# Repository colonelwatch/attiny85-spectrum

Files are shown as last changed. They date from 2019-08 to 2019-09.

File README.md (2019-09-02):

# attiny85-spectrum

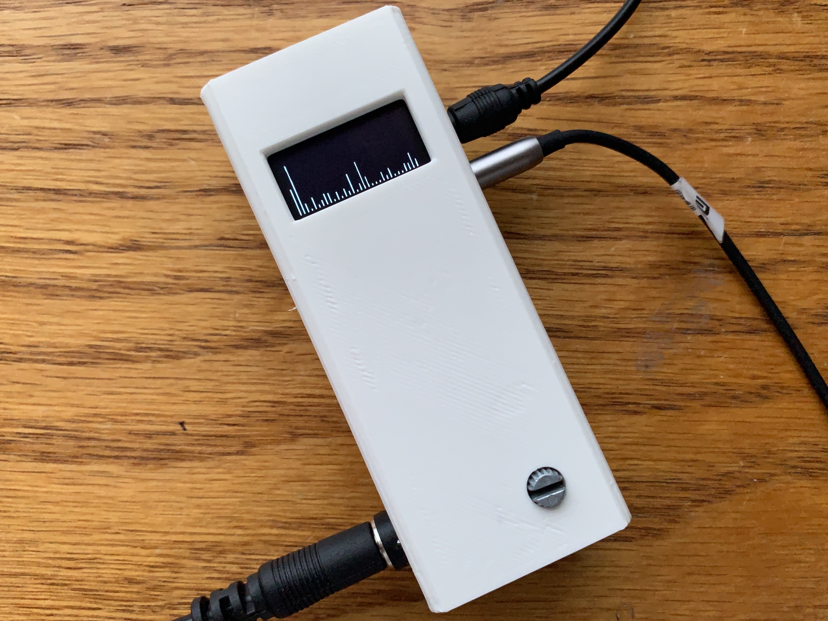
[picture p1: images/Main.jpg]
Main Image


The goal of this project is to get smooth, appealing music visualization on the ATTiny85, optimizing around its limited speed and resources (RAM and program memory). Its on ongoing personal project right now which is mostly complete (outside help is still welcome!), but it's otherwise fully functional and ready to be flashed. Some special steps are required, however, and will be listed below. *Thanks goes to redditors stockvu and mashuptwice for their input on time-smoothing.*

## Explanation
The linchpins to enabling music visualization with an ATTiny85 are two libraries: 

- kosme's AVR implementation of [fix_fft](https://github.com/kosme/fix_fft), a faster 8-bit integer-based FFT
- lexus2k's [ssd1306](https://github.com/lexus2k/ssd1306) library and its nanoengine API, which outputs to the OLED in 32x32 chunks because the ATTiny85 can't hold the entire screen in memory

I had to change the pin assignments in the ssd1306 library to free up an analog-capable pin, ~~and in the fix_fft library I changed the char type buffers into int8_t ones~~. Both modified libraries are availible, and they must be placed in the Arduino libraries folder, overwriting the original ones (keep a backup!). *Recently kosme has updated the fix_fft library to int8_t defintions as well, __I have now included his latest commit instead__.* Additionally, I raised the OSCCAL value to 250, giving me an internal clock of about 30MHz. It's usually used for clock calibration, but it has been used successfully for overclocking. However, it's only found on the ATTiny85 and a few other Atmel MCUs.

The core of the program is a loop of this:

1. The music is sampled with the ADC at pin 3/A3, which is then mapped to the range that int8_t covers (0 to 1023 -> -128 to 127)
     * A prescaler of ~~16~~ 32 gives a sampling frequency of about ~~2MHz~~ *now 1MHz* (considering the overclock), so empty while loops are used to maintain the user-set sampling frequency
2. The average value is subtracted from all samples. This lets the first band represent extremely low frequencies, rather than being swamped with the DC bias
3. The "fix_fftr" function, which runs twice as fast as and uses half the memory of the "fix_fft" version because it doesn't need imaginary data
4. The output is reordered, cut off below 0, scaled up, and time-smoothed using the previous output and fixed factors
5. The modified output is fed into the OLED part-by-part using the nanoengine API

## Components

- ATTiny85
- SSD1306 OLED Module
- 3-Pole Audio Jack (1, 2 for pass-through)
- 2N3904 or other NPN transistor
- 0.1uF Capacitor
- Potentiometer, any value above 10k
- 200 Ohm Resistor (2)
- 820 Ohm Resistor
- 100k Ohm Resistor
- External 5V Power Supply

## Schematic

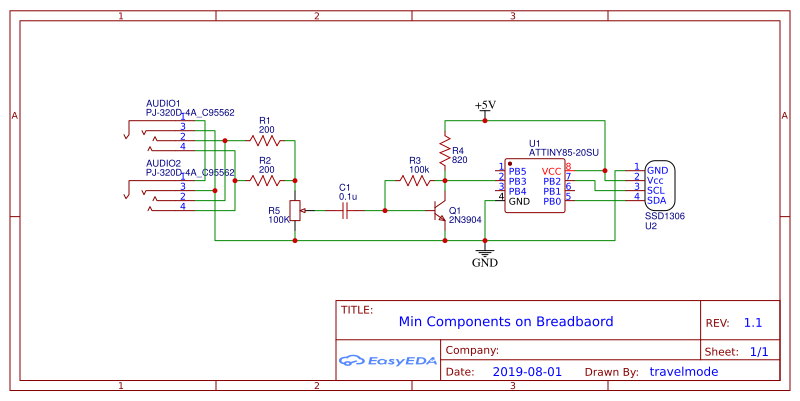
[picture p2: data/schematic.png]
Schematic


## Demonstration

attiny85-spectrum demonstration (https://www.youtube.com/watch?v=iyPTCbWjp_4)

### Enclosure

The STL of the enclosure in the video is included in this repo. Printed on a Monoprice Select Mini V2. See [this](images/Inside.jpg) picture for component placements on a 3x7 protoboard. *Note: The barrel connector wire colors were accidentally swapped—red is ground, and black is 5V. Please correct this if you intend to replicate the entire project!*

## Limitations/TO-DO

- The fix_fft library uses linear scaling for both frequency and power... and without much resolution in either / ~~*No room for logarithmic scaling? TO-DO: Attempt to implement later.*~~
- The OLED display regularly shows detached bars that only really appear in still photos / *TO-DO: Find out why*
    - Apparently has reduced intensity now with recent code changes. Still unexplained though.

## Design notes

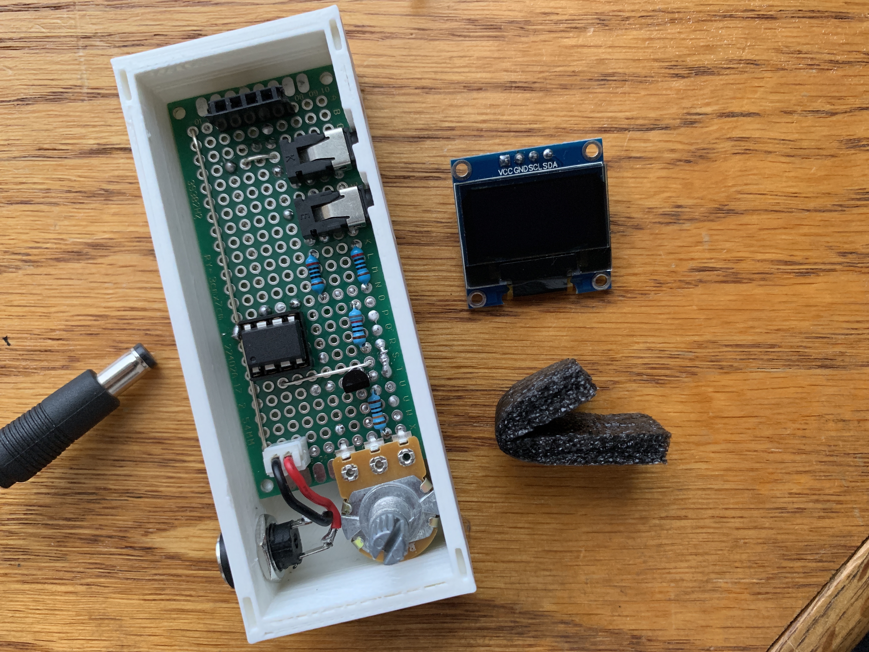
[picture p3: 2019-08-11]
images/Inside.jpg

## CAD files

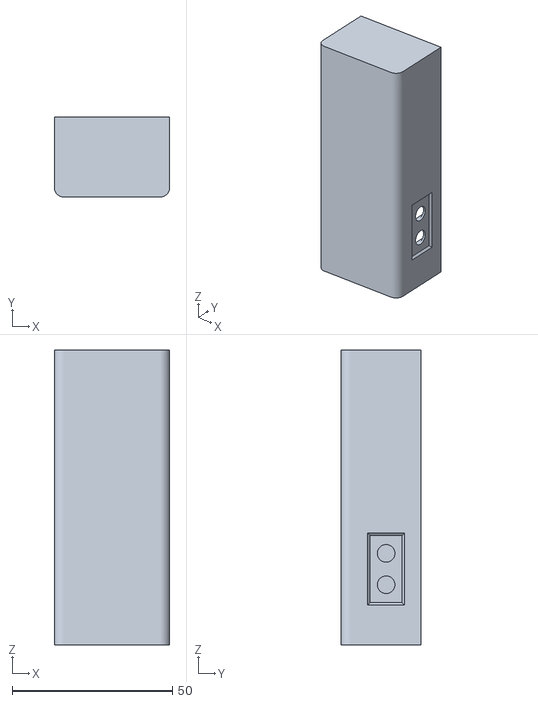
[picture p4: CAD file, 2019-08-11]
data/OLED Spectrum Body.stl
36.0 x 25.0 x 92.0

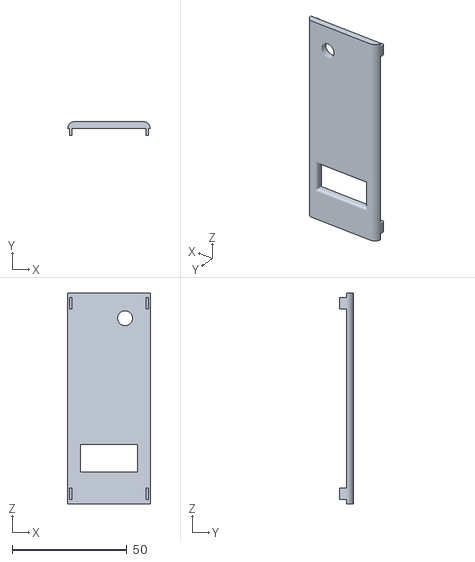
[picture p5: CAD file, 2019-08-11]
data/OLED Sprectrum Front.stl
36.0 x 6.00 x 92.0

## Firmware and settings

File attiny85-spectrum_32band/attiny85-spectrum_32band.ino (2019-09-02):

// Copyright [2019] [colonelwatch]

#include "fix_fft.h"                  // 8-bit FFT library modified for Arduino
#include "ssd1306.h"                  // library for OLED
#include "nano_engine.h"              // library for nanoengine (which draws sector-by-sector on OLED because the ATtiny85 can't hold a full buffer)

// To get this program to operate, the SDA and SCL pins must be reassigned to 0 and 2 respectively in the library header file
// The file is located in libraries\ssd1306\src\intf\i2c\ssd1306_i2c_conf.h
// Make sure to undo this if the library will be used again in the future

// These are user-adjustable
//#define LOG_OUTPUT              // Uncomment to enable logarithmic output (exchanges absolute resoluton for more readable output; may require different below params)
#define SAMPLING_FREQUENCY 15000  // Sampling frequency (Actual max measured frequency captured is half)
#define TIME_FACTOR 3             // Smoothing factor (lower is more dynamic, higher is smoother) ranging from 1 to 10+
#define SCALE_FACTOR 8           // Direct scaling factor (raise for higher bars, lower for shorter bars)

#ifdef LOG_OUTPUT
const float log_scale = 64./log(64./SCALE_FACTOR + 1.);                              // Attempts to create an equivalent to SCALE_FACTOR for log function
#endif
const float coeff = 1./TIME_FACTOR;                                                  // Time smoothing coefficients (used to factor in previous data)
const float anti_coeff = (TIME_FACTOR-1.)/TIME_FACTOR;
const unsigned int sampling_period_us = round(1000000 * (2.0 / SAMPLING_FREQUENCY)); // Sampling period (doubled to account for overclock)

int8_t data[64], buff[32];                                     // used to store FFT input/output and past data
unsigned long microseconds;                                    // used for timekeeping
int summ, avg;                                                 // used for DC bias elimination

NanoEngine<TILE_32x32_MONO> engine;                            // declares nanoengine

void setup()
{
  OSCCAL = 250; // Overclocks the MCU to around 30 MHz, set lower if this causes instability, raise if you can/want
  
  ADCSRA &= ~(bit (ADPS0) | bit (ADPS1) | bit (ADPS2));       // clear ADC prescaler bits
  ADCSRA |= bit (ADPS2);                                      // sets ADC clock in excess of 10kHz
  ADCSRA |= bit (ADPS0);

  ssd1306_128x64_i2c_init();                                  // initializes OLED
  ssd1306_clearScreen();                                      // clears OLED
  
  engine.begin();                                             // inititalizes nanoengine
};

void loop()
{
  summ = 0;
  for (int i = 0; i < 64; i++) {
    microseconds = micros();
    
    data[i] = ((analogRead(A3)) >> 2) - 128;                        // Fitting analogRead data (range:0 - 1023) to int8_t array (range:-128 - 127)
    summ += data[i];
    while (micros() < (microseconds + sampling_period_us)) {        // Timing out uC ADC to fulfill sampling frequency requirement
    }
  }

  // Eliminating remaining DC component (produces usable data in FFT bin #0, which is usually swamped by DC bias)
  avg = summ/64;
  for (int i = 0; i < 64; i++){
    data[i] -= avg;
  }
    
  fix_fftr(data, 6, 0);                             // Performing real FFT

  // Reordering the data so that the left/right halves become odd/even, based on apparent fix_fftr output
  // Seems to make it more accurate (proper response to a frequency sweep with some aliasing)
  {int8_t reordered[32];  // <-- This array as a global variable causes instablity, so it's declared in a minimal scope
    for(int i = 0; i < 32; i++){
    if(i % 2 != 0) reordered[i] = data[i/2+16];
    else reordered[i] = data[i/2];
  }for(int i = 0; i < 32; i++) data[i] = reordered[i];}
  
  // Time smoothing by user-determined factor and user-determined scaling
  for(int count = 0; count < 32; count++){
  if(data[count] < 0) data[count] = 0;                                          // Eliminating negative output of fix_fftr
  #ifdef LOG_OUTPUT
  else data[count] = log_scale*log((float)(data[count]+1));                     // Logarithmic function equivalent to SCALING_FACTOR*log2(x+1)
  #else
  else data[count] *= SCALE_FACTOR;                                             // Linear scaling up according to SCALE_FACTOR
  #endif
  data[count] = (float)buff[count] * anti_coeff + (float)data[count] * coeff;   // Smoothing by factoring in past data
  buff[count] = data[count];                                                    // Storing current output as next frame's past data
  if(data[count] > 63) data[count] = 63;                                        // Capping output at screen height
  }
  
  // Output to SSD1306 using nanoengine canvas from library
  engine.refresh();                                               // Mark entire screen to be refreshed
  engine.canvas.clear();                                          // Clear canvas as previous data
  for(int i = 0; i < 8; i++){
    engine.canvas.drawVLine(i*4,31-(data[i]+1),31);          // Draw to canvas data for lower-leftest sector (FFT bins 0 - 7, lower half)
  }
  engine.canvas.blt(0,32);                                        // Outputs canvas to OLED with an offset (x pixels, y pixels)
  engine.canvas.clear();
  for(int i = 0; i < 8; i++){
    if(data[i] > 31) engine.canvas.drawVLine(i*4,31-(data[i]-31),31);     // Draw to canvas data for upper-leftest sector (FFT bins 0 - 7, upper half)
  }
  engine.canvas.blt(0,0);
  engine.canvas.clear();
  for(int i = 8; i < 16; i++){
    engine.canvas.drawVLine((i-8)*4,31-(data[i]+1),31);      // FFT bins 8 - 15, lower half
  }
  engine.canvas.blt(32,32);  
  engine.canvas.clear();
  for(int i = 8; i < 16; i++){
    if(data[i] > 31) engine.canvas.drawVLine((i-8)*4,31-(data[i]-31),31);   // FFT bins 9 - 15, upper half
  }
  engine.canvas.blt(32,0);
  engine.canvas.clear();
  for(int i = 16; i < 24; i++){
    engine.canvas.drawVLine((i-16)*4,31-(data[i]+1),31);     // FFT bins 16 - 23, lower half
  }
  engine.canvas.blt(64,32);
  engine.canvas.clear();
  for(int i = 16; i < 24; i++){
    if(data[i] > 31) engine.canvas.drawVLine((i-16)*4,31-(data[i]-31),31);  // FFT bins 16 - 23, upper half 
  }
  engine.canvas.blt(64,0);
  engine.canvas.clear();
  for(int i = 24; i < 32; i++){
    engine.canvas.drawVLine((i-24)*4,31-(data[i]+1),31);     // FFT bins 24 - 31, lower half
  }
  engine.canvas.blt(96,32);
  engine.canvas.clear();
  for(int i = 24; i < 32; i++){
    if(data[i] > 31) engine.canvas.drawVLine((i-24)*4,31-(data[i]-31),31);  // FFT bins 24 - 31, upper half
  }
  engine.canvas.blt(96,0);
}

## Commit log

2019-08-11 New README.md, pictures, stl, and updated code
    Removed the 64-bar version because it was too far behind, stl shown in demonstration uploaded, pictures, new README, and cleaned up some mistakes in code
    [OLED Spectrum Body.stl, OLED Sprectrum Front.stl]
2019-08-13 Reddit-suggested changes + cleanup
    - Eliminated unnecessary code and corrected a typo.
    - Made height scaling configurable
    - Slowed down ADC for better accuracy
    - Lower sampling frequency
    - New, configurable smoothing code thanks to redditors stockvu and mashuptwice
    - Coincidentally, much of the disconnected-bars issue had resolved itself, except for in the first band
    [attiny85-spectrum_32band.ino]
2019-08-14 Fix precedence bug (#4)
    * Fix precedence bug
    *Default scaling changed
    *Data ceiling added.
    *Unnecessary code removed
    [attiny85-spectrum_32band.ino]
